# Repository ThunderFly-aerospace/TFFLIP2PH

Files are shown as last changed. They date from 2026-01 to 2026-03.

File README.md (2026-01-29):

# TFFLIP2PH - Flipper Zero to Pixhawk peripheral adapter

TFFLIP2PH is a compact hardware adapter that allows [Flipper Zero](https://flipper.net) to interface with peripherals using the Pixhawk / Dronecode connector standard. The board exposes common Pixhawk-style peripheral interfaces (UART, I2C, SPI, PWM) and provides regulated 5 V peripheral power, enabling rapid sensor prototyping, testing, and demonstration directly from Flipper Zero. This project is intended as a development and experimental tool, not as a flight controller or flight-qualified hardware.

## Features

* Flipper Zero GPIO to Pixhawk-compatible JST-GH connectors
* Supported interfaces:

  * UART (peripheral devices, telemetry, modems)
  * I2C (sensors)
  * SPI (high-speed sensors)
  * PWM (RC servos, basic actuator testing)
* 5 V peripheral power supply (from Flipper Zero)
* Compact form factor suitable for flat sensors mounting on the back of Flipper Zero
* Designed as a [Small external module](https://docs.flipper.net/zero/development/hardware/modules-blueprints#NIlXe) for Flipper Zero

## Typical use cases

* Rapid prototyping of sensors with Flipper Zero
* Bringing up new hardware using UART / I2C / SPI
* Laboratory testing and output control
* Educational and demonstration purposes
* Basic [servo testing via PWM](https://github.com/ThunderFly-aerospace/flipper-servotester)
* Internal testing and QA tooling

## Construction notes

* Peripheral connectors follow Pixhawk (Dronecode) standard pinouts**
* Peripheral power output: 5 V @ 1A
* Power is sourced from the Flipper Zero switching power supply
* Users are responsible for verifying:

  * Maximal current consumption
  * voltage compatibility
  * signal level requirements of connected devices

⚠️ **Do not connect this board to a powered Pixhawk autopilot or other flight hardware.**

## Mechanical concept

The board is designed to be mounted flat at the top of Flipper Zero, with connectors oriented parallel to the PCB surface. This allows attached peripherals to be mechanically fixed using tape or hook-and-loop fasteners on the back of the flipper zero for portable experimentation.

PCB is designed in the way that only one side is populated by JST connectors. Therefore, there exist two variants for use.

### "Flight controller" mode

In this configuration, the Flipper acts as a "Flight Controller" and connected devices are peripherals. 

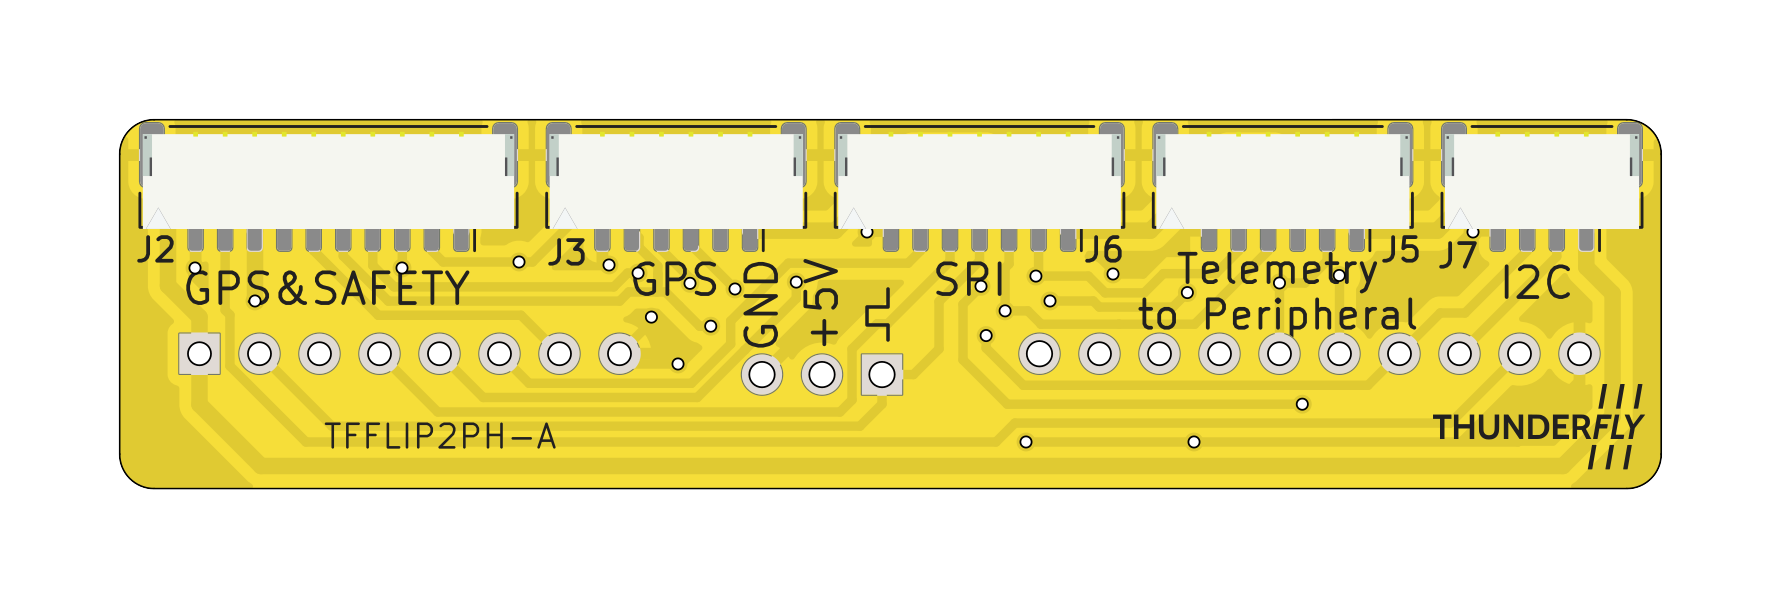
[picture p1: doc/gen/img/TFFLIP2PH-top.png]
TFFLIP2PH top view


### TF Payload mode

This use case sets Flipper as a "Payload device". The Flipper is therefore connected between [TFGPS](https://docs.thunderfly.cz/avionics/TFGPS01/) and a flight controller. 

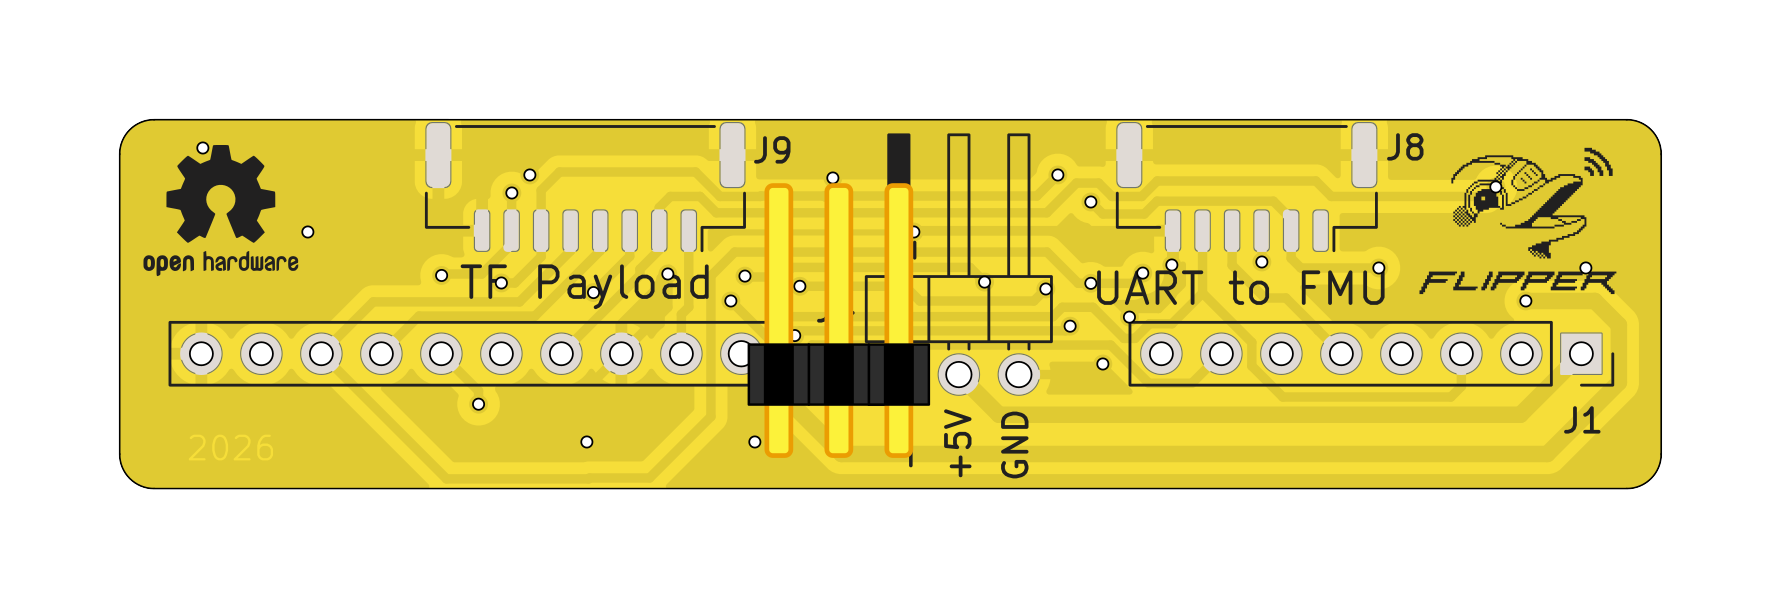
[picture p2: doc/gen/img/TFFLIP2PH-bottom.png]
TFFLIP2PH bottom view


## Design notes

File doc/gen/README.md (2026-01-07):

# PCB

Board size: 65.34x15.7 mm (2.57x0.62 inches)

- This is the size of the rectangle that contains the board
- Thickness: 1.2 mm (47 mils)
- Material: FR4
- Finish: None
- Layers: 2
- Copper thickness: 35 µm

Solder mask: TOP / BOTTOM

- Color: Green

Silk screen: TOP / BOTTOM

- Color: White

Stackup:

| Name | Type | Color | Thickness [µm]| Material | Er | Loss tan |
|---|---|---|---|---|---|---|
| F.SilkS | Top Silk Screen | | | | | |
| F.Paste | Top Solder Paste | | | | | |
| F.Mask | Top Solder Mask | | 10 | | | |
| F.Cu | copper | | 35 | | | |
| dielectric 1 | core | | 1110 | FR4 | 4.5 | 0.020 |
| B.Cu | copper | | 35 | | | |
| B.Mask | Bottom Solder Mask | | 10 | | | |
| B.Paste | Bottom Solder Paste  | | | | | |
| B.SilkS | Bottom Silk Screen | | | | | |

# Important sizes

Clearance: 0.2 mm (8 mils)

Track width: 0.4 mm (16 mils)

- By design rules: 0.2 mm (8 mils)

Drill: 0.5 mm (20 mils)

- Vias: 0.5 mm (20 mils) [Design: 0.4 mm (16 mils)]
- Pads: 1.0 mm (39 mils)
- The above values are real drill sizes, they add 0.1 mm (4 mils) to plated holes (PTH)

Via: 0.8/0.4 mm (31/16 mils)

- By design rules: 0.8/0.3 mm (31/12 mils)
- Micro via: yes [0.2/0.1 mm (8/4 mils)]
- Buried/blind via: yes
- Total: 33 (thru: 33 buried/blind: 0 micro: 0)

Outer Annular Ring: 0.15 mm (6 mils)

- By design rules: 0.3 mm (12 mils)

Eurocircuits class: 4B
- Using min drill 0.5 mm for an OAR of 0.15 mm

# General stats

Components count: (SMD/THT)

- Top: 5/0 (SMD)
- Bottom: 2/2 (SMD + THT)

Defined tracks:

- 0.25 mm (10 mils)
- 0.3 mm (12 mils)
- 0.4 mm (16 mils)
- 0.5 mm (20 mils)
- 0.6 mm (24 mils)
- 0.7 mm (28 mils)
- 0.8 mm (31 mils)

Used tracks:

- 0.4 mm (16 mils) (294) defined: yes
- 0.7 mm (28 mils) (46) defined: yes

Defined vias:

Used vias:

- 0.8/0.4 mm (31/16 mils) (Count: 33, Aspect: 1.5 A) defined: no

Holes (excluding vias):

- 0.9 mm (35 mils) (17)
- 1.0 mm (39 mils) (4)

Oval holes:

Drill tools (including vias and computing adjusts and rounding):

- 0.5 mm (20 mils) (33)
- 1.0 mm (39 mils) (17)
- 1.1 mm (43 mils) (4)

Solder paste stats:

Using a paste with 87.75 % alloy, that has an specific gravity for the alloy of 7.4 g/cm³
and 1.0 g/cm³ for the flux. This paste has an specific gravity of  4.15 g/cm³.

The stencil thickness is  0.12 mm.

| Side | Pads with paste | Area [mm²] | Paste [g] |
|---|---|---|---|
| Top | 43 | 59.38 | 0.30 |
| Bottom | 18 | 24.55 | 0.12 |
| Total  | 61 | 83.93 | 0.42 |

Note: this is just an approximation to the theoretical value. Margins of the solder mask and waste aren't computed.

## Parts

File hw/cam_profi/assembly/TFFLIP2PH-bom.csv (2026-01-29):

Component | Description | Part | References | Value | Footprint | Quantity Per PCB | Datasheet | ust_id
1 | 1x03 2.54 mm pitch header | HEADER_1x03 | J4 | Angled Pinheader | PinHeader_1x03_P2.54mm_Horizontal | 1 | 5c70984412875079b91f879d
2 | Flipper Zero is a portable multi-tool for pentesters and geeks in a toy-like body | Flipper_Zero | J1 | Flipper_Zero | Flipper_Zero_Straight | 1 | https://docs.flipper.net/development
3 |  | SM04B-GHS-TB | J7 | SM04B-GHS-TB | JST_GH_SM04B-GHS-TB_1x04-1MP_P1.25mm_Horizontal | 1 |  | 5c86273d1287500b4e0280be
4 | 1x07 2.54 mm pitch header | SM06B-GHS-TB | J3J5 | SM06B-GHS-TB | JST_GH_SM06B-GHS-TB_1x06-1MP_P1.25mm_Horizontal | 2 |  | 5fa0f70212875025b3977932
5 | 1x08 2.54 mm pitch header | SM07B-GHS-TB | J6 | SM07B-GHS-TB | JST_GH_SM07B-GHS-TB_1x07-1MP_P1.25mm_Horizontal | 1 |  | 5c7250081287500b4e112e78
6 | Zásuvka; kabel-pl.spoj; vidlice; GH; 1,25mm; PIN: 10; SMT; 50V; 1A | SM10B-GHS-TB | J2 | SM10B-GHS-TB | JST_GH_SM10B-GHS-TB_1x10-1MP_P1.25mm_Horizontal | 1 |  | 5fa0f69e12875025b397791d

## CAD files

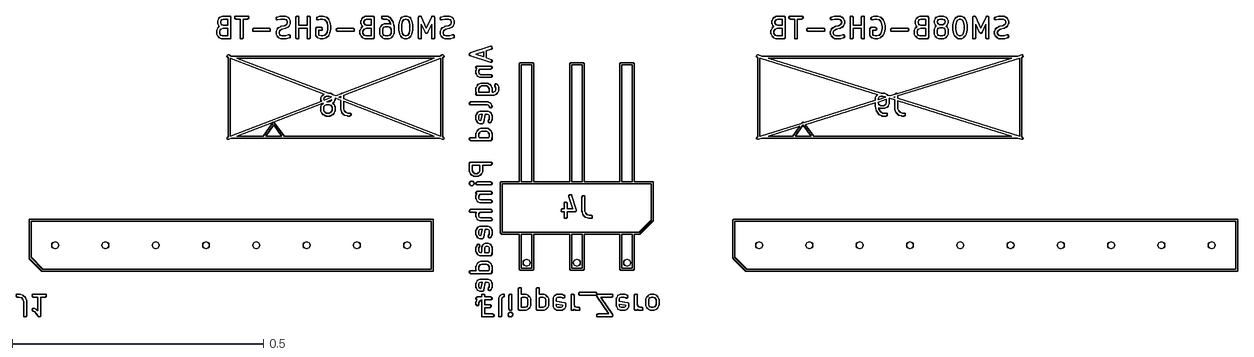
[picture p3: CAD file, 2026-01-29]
doc/gen/dxf/TFFLIP2PH-B_Fab.dxf
2.43 x 0.598

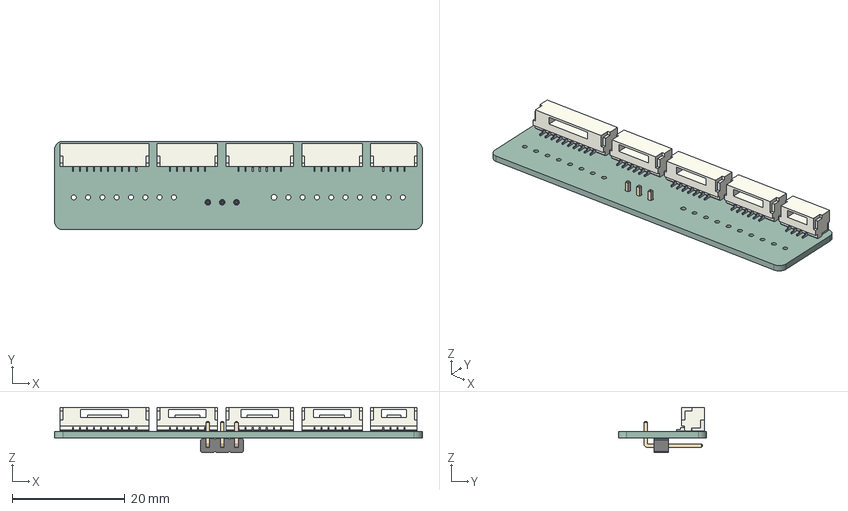
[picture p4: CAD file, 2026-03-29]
doc/gen/TFFLIP2PH.step
65.3 x 15.7 x 8.07 mm
JST_GH_SM04B-GHS-TB_1x04-1MP_P1.25mm_Horizontal
JST_GH_SM10B-GHS-TB_1x10-1MP_P1.25mm_Horizontal
JST_GH_SM06B-GHS-TB_1x06-1MP_P1.25mm_Horizontal x 2
JST_GH_SM07B-GHS-TB_1x07-1MP_P1.25mm_Horizontal
PinHeader_1x03_P2.54mm_Horizontal
kibot__w3e8fdu_PCB

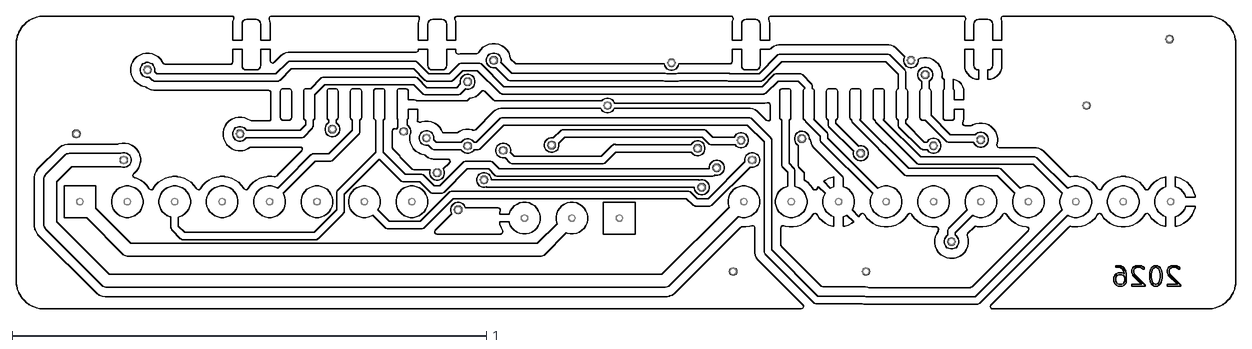
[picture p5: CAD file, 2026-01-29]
doc/gen/dxf/TFFLIP2PH-B_Cu.dxf
2.57 x 0.617

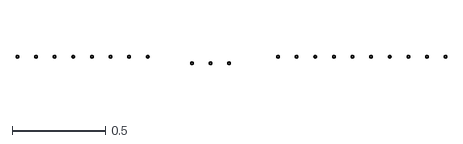
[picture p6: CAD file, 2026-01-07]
doc/gen/dxf/TFFLIP2PH-User_Eco1.dxf
2.31 x 0.0485

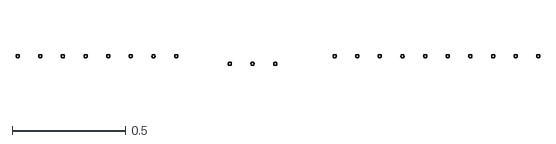
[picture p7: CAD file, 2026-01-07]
doc/gen/dxf/TFFLIP2PH-F_Adhesive.dxf
2.31 x 0.0485

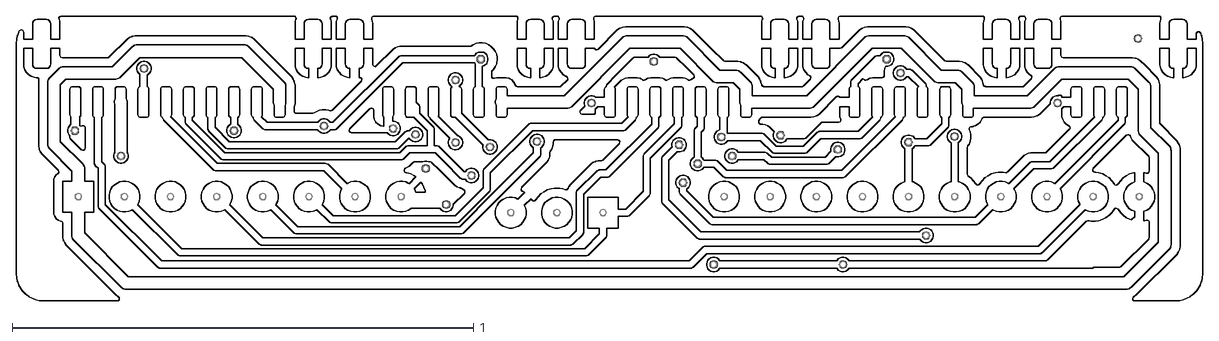
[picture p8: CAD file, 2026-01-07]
doc/gen/dxf/TFFLIP2PH-F_Cu.dxf
2.57 x 0.617

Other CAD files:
doc/gen/dxf/TFFLIP2PH-B_Courtyard.dxf
doc/gen/dxf/TFFLIP2PH-B_Mask.dxf
doc/gen/dxf/TFFLIP2PH-B_Silkscreen.dxf
doc/gen/dxf/TFFLIP2PH-Edge_Cuts.dxf
doc/gen/dxf/TFFLIP2PH-F_Courtyard.dxf
doc/gen/dxf/TFFLIP2PH-F_Fab.dxf
doc/gen/dxf/TFFLIP2PH-F_Mask.dxf
doc/gen/dxf/TFFLIP2PH-F_Paste.dxf
doc/gen/dxf/TFFLIP2PH-F_Silkscreen.dxf

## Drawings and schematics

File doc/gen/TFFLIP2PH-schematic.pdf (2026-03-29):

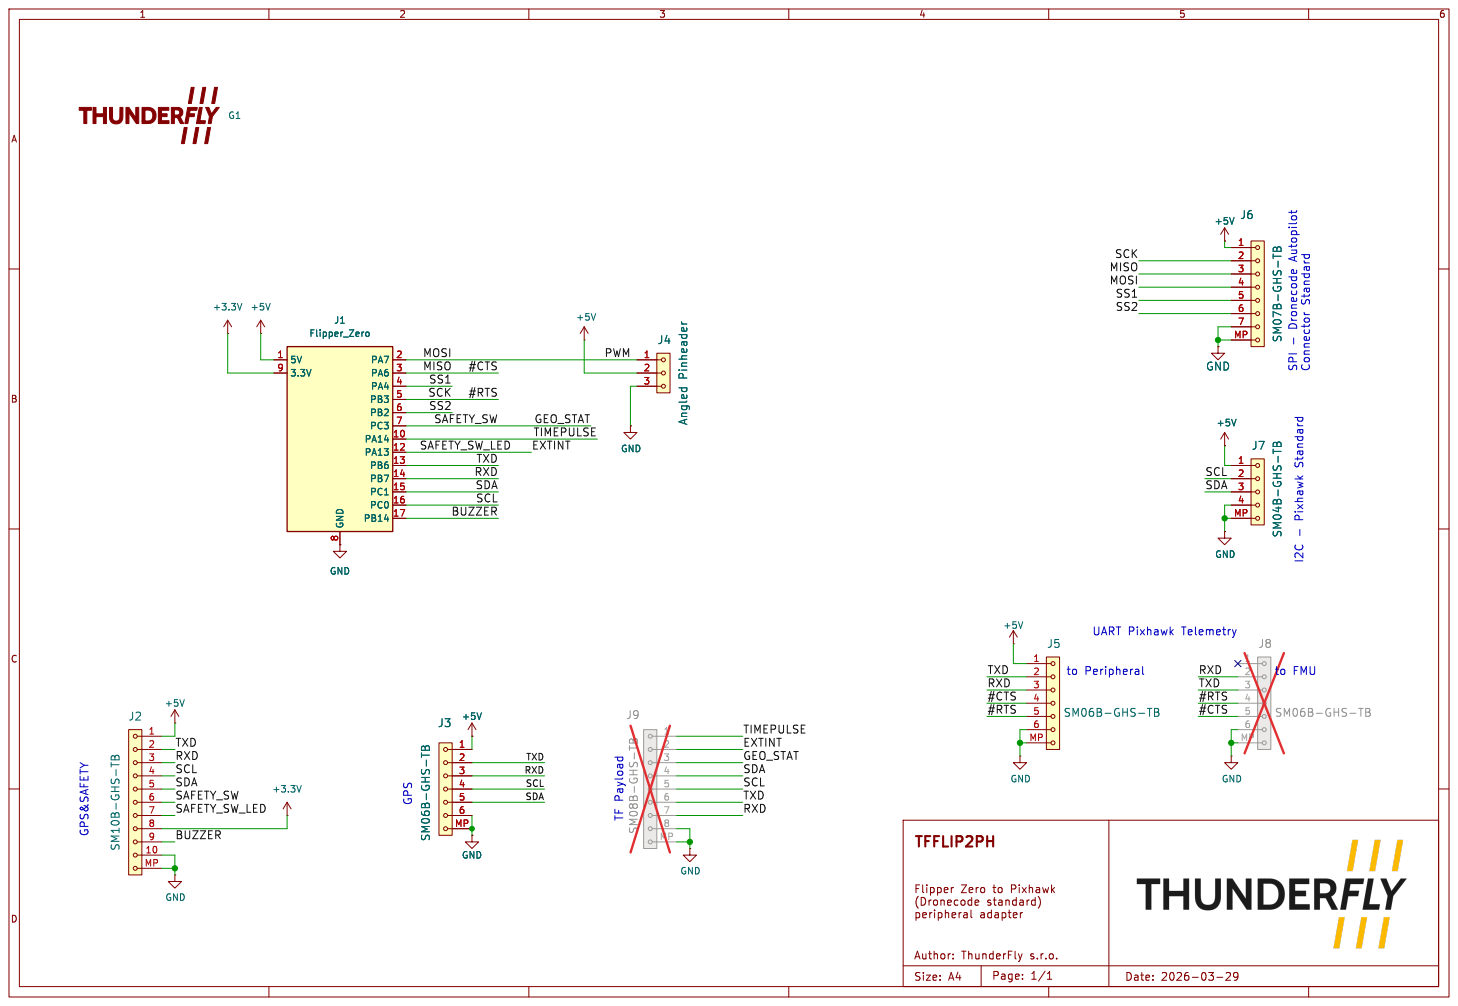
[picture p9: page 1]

to Peripheral GPS&SAFETY
J2 SM10B-GHS-TB

Flipper Zero to Pixhawk

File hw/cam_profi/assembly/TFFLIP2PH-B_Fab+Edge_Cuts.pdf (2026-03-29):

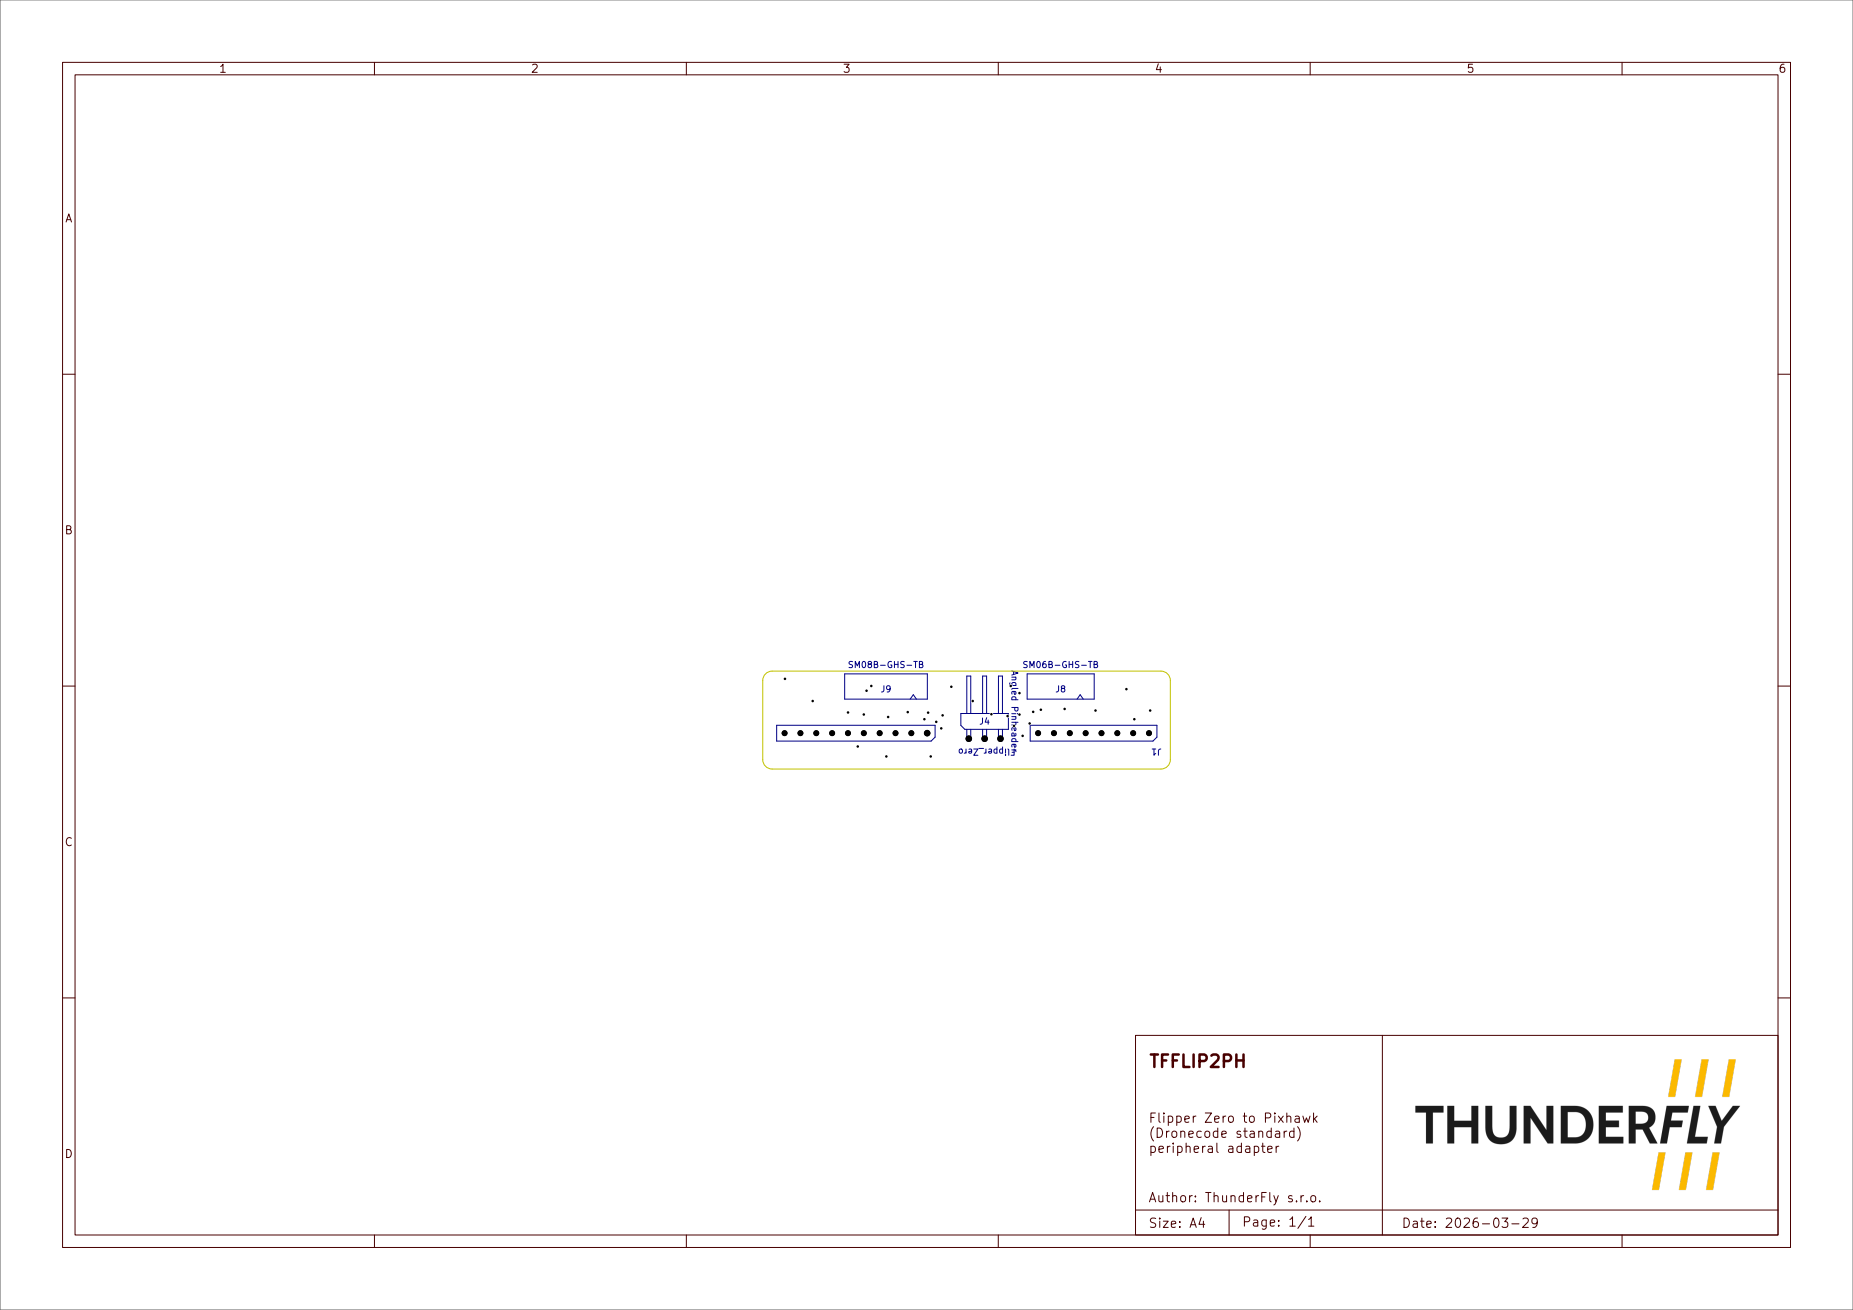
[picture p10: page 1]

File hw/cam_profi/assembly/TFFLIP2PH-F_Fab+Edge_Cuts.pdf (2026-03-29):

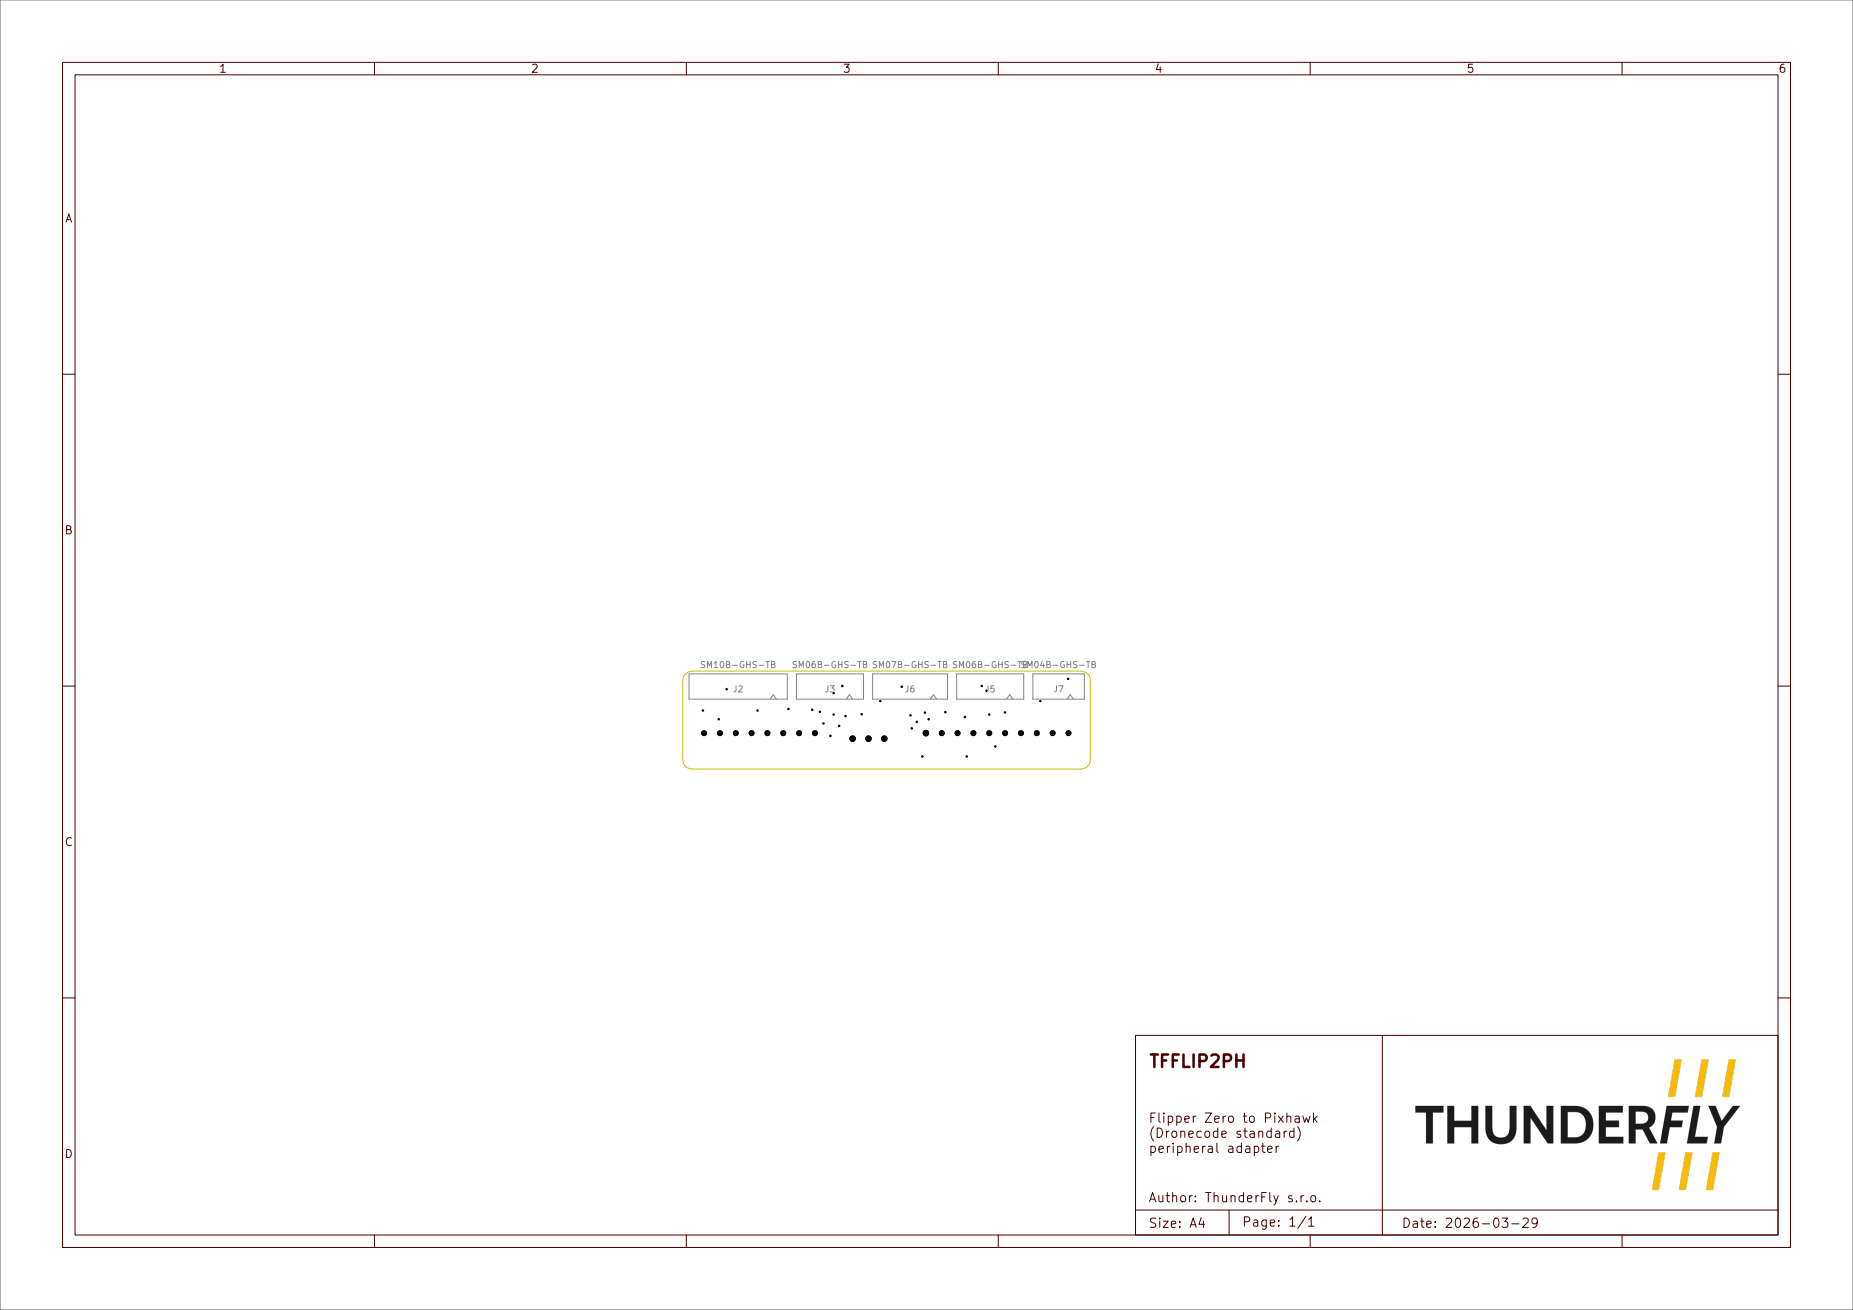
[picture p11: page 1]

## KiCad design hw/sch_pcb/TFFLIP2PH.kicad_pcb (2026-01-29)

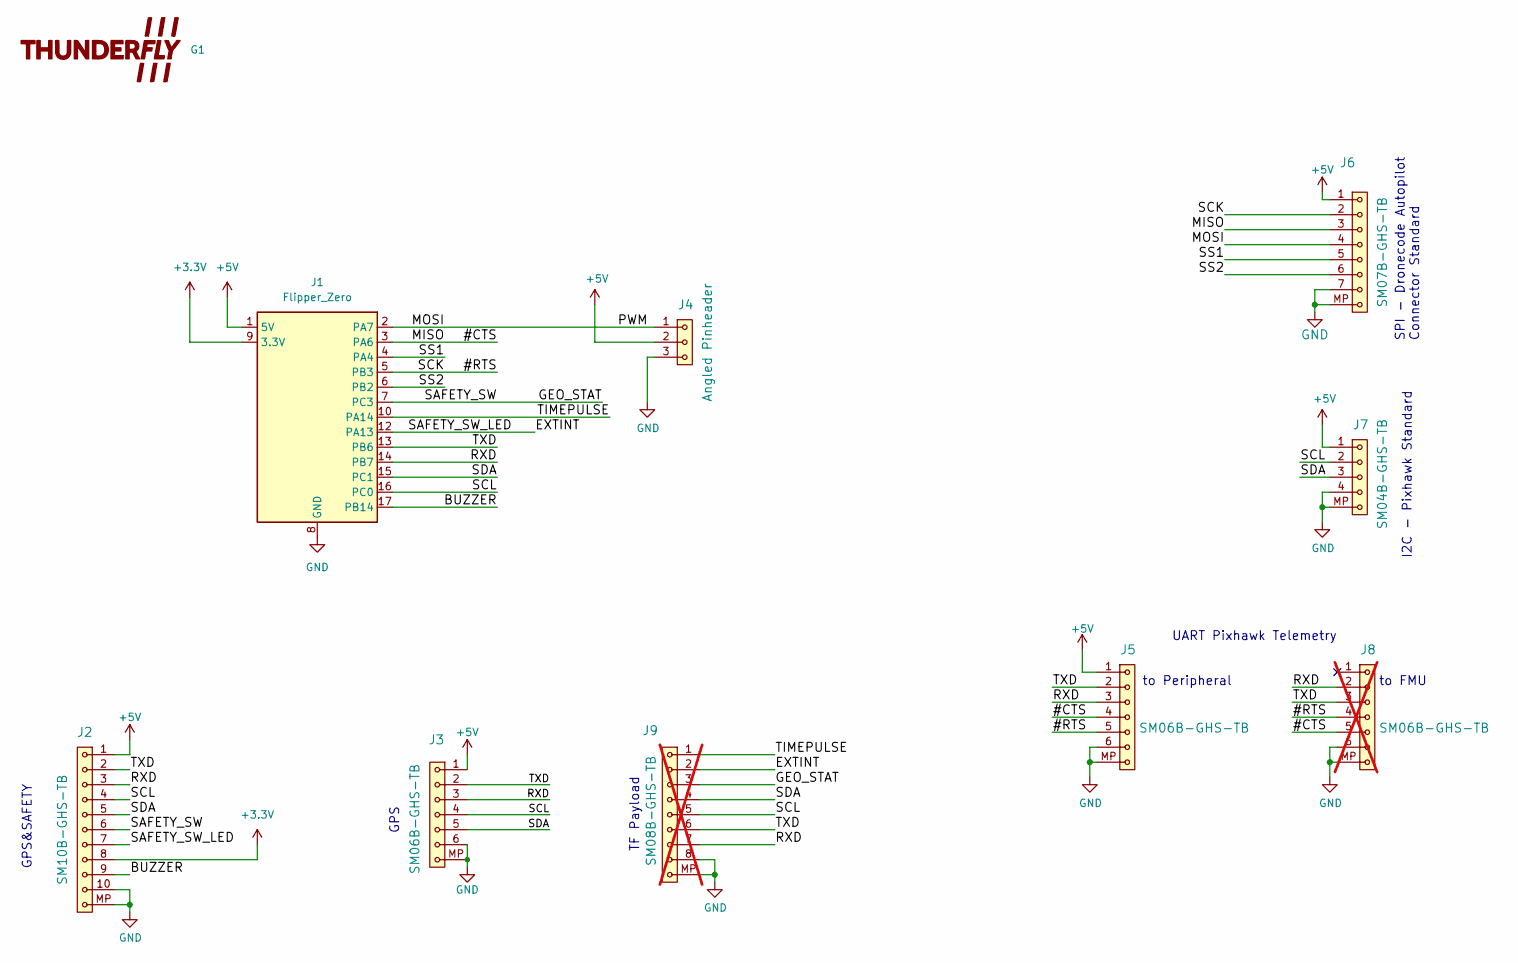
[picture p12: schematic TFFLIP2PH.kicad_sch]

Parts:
G1: LOGO; TF 10x4,7
J1: Flipper_Zero; Flipper_Zero_Straight
J2: SM10B-GHS-TB; JST_GH_SM10B-GHS-TB_1x10-1MP_P1.25mm_Horizontal
J3, J5: SM06B-GHS-TB; JST_GH_SM06B-GHS-TB_1x06-1MP_P1.25mm_Horizontal
J4: Angled Pinheader; PinHeader_1x03_P2.54mm_Horizontal
J6: SM07B-GHS-TB; JST_GH_SM07B-GHS-TB_1x07-1MP_P1.25mm_Horizontal
J7: SM04B-GHS-TB; JST_GH_SM04B-GHS-TB_1x04-1MP_P1.25mm_Horizontal
J8: SM06B-GHS-TB; JST_GH_SM06B-GHS-TB_1x06-1MP_P1.25mm_Horizontal; not fitted
J9: SM08B-GHS-TB; JST_GH_SM08B-GHS-TB_1x08-1MP_P1.25mm_Horizontal; not fitted

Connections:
+3.3V: J1.9 (3.3V), J2.8
+5V: J1.1 (5V), J2.1, J3.1, J4.2, J5.1, J6.1, J7.1
/#CTS: J1.3 (PA6), J5.4, J6.3, J8.5
/#RTS: J1.5 (PB3), J5.5, J6.2, J8.4
/BUZZER: J1.17 (PB14), J2.9
/EXTINT: J1.12 (PA13), J2.7, J9.2
/GEO_STAT: J1.7 (PC3), J2.6, J9.3
/MOSI: J1.2 (PA7), J4.1, J6.4
/RXD: J1.14 (PB7), J2.3, J3.3, J5.3, J8.2, J9.7
/SCL: J1.16 (PC0), J2.4, J3.4, J7.2, J9.5
/SDA: J1.15 (PC1), J2.5, J3.5, J7.3, J9.4
/SS1: J1.4 (PA4), J6.5
/SS2: J1.6 (PB2), J6.6
/TIMEPULSE: J1.10 (PA14), J9.1
/TXD: J1.13 (PB6), J2.2, J3.2, J5.2, J8.3, J9.6
GND: J1.8 (GND), J1.11 (GND), J1.18 (GND), J2.10, J2.MP, J3.6, J3.MP, J4.3, J5.6, J5.MP, J6.7, J6.MP, J7.4, J7.MP, J8.6, J8.MP, J9.8, J9.MP

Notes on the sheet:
GPS
UART Pixhawk Telemetry
to FMU
SPI - Dronecode Autopilot Connector Standard
I2C - Pixhawk Standard
TF Payload
to Peripheral
GPS&SAFETY

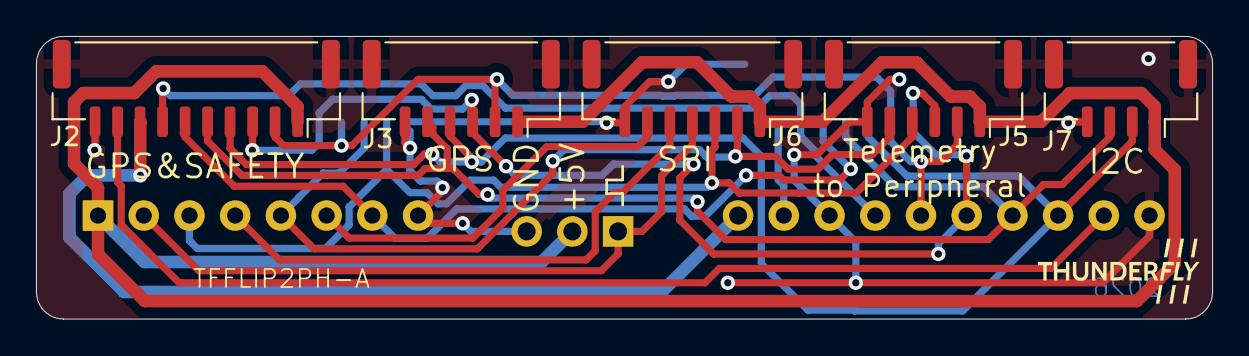
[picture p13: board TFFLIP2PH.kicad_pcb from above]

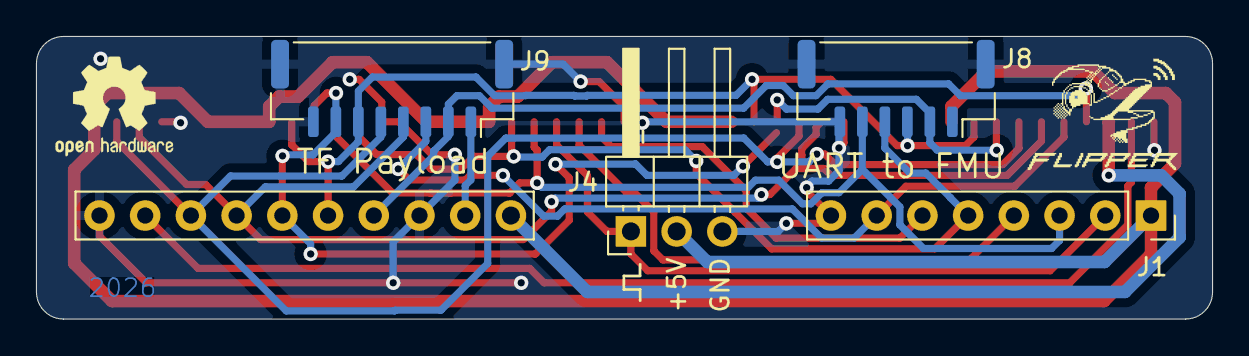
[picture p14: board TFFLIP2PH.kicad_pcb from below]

Board: 2 copper layers, 65.3 x 15.7 mm, 10 parts (4 on the bottom side), 16 nets.

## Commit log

2026-01-02 Initial template of Flipper Zero small module.
    [TFFLIP2PH-A.kicad_pcb, TFFLIP2PH-A.kicad_sch]
2026-01-02 Fix KiCAD project name.
    [TFFLIP2PH.kicad_pcb, TFFLIP2PH.kicad_sch]
2026-01-02 Update actions products
    [TFFLIP2PH-A-B_Cu.gbr, TFFLIP2PH-A-B_Mask.gbr, TFFLIP2PH-A-B_Paste.gbr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]
2026-01-02 Swap board sides to match top view on flipper zero.
    [TFFLIP2PH.kicad_pcb, TFFLIP2PH.kicad_sch]
2026-01-02 Fix pin-header orientation.
    [TFFLIP2PH.kicad_pcb]
2026-01-02 Update README.md
    Add PCB images.
2026-01-02 Restore accidentally deleted OSHW logo.
    [TFFLIP2PH.kicad_pcb]
2026-01-03 Initial set of connectors.
    [TFFLIP2PH.kicad_pcb, TFFLIP2PH.kicad_sch]
2026-01-05 Routing in progress.
    [TFFLIP2PH.kicad_pcb, TFFLIP2PH.kicad_sch]
2026-01-07 Fully routed PCB.
    [TFFLIP2PH.kicad_pcb]
2026-01-07 Fix DRC errors.
    [TFFLIP2PH.kicad_pcb]
2026-01-07 Improve layout and silkscreen.
    [TFFLIP2PH.kicad_pcb, TFFLIP2PH.kicad_sch]
2026-01-29 Fixed #1
    [TFFLIP2PH.kicad_pcb]
2026-01-29 Update silkscreen and manufacturing attributes.
    [TFFLIP2PH.kicad_pcb, TFFLIP2PH.kicad_sch]
2026-02-15 Automatic update of KiCAD outputs
    [TFFLIP2PH-A-B_Cu.gbr, TFFLIP2PH-A-B_Mask.gbr, TFFLIP2PH-A-B_Paste.gbr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]
